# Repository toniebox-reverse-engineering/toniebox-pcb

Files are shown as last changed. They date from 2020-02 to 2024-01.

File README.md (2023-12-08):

# Toniebox PCB

Repository which will lead to a complete schematic of a Toniebox PCB. The schematic is done with KiCad.

View this project on [CADLAB.io](https://cadlab.io/project/2472). 

Source of CC3200 footprint: https://raw.githubusercontent.com/Turegano/CC3200/master/lib/CC3200.lib

## Table Of Contents
- [Toniebox PCB](#toniebox-pcb)
  - [Table Of Contents](#table-of-contents)
  - [Folders](#folders)
  - [Status](#status)
    - [Remaining Work](#remaining-work)
  - [Block Diagrams](#block-diagrams)
  - [Testpoints](#testpoints)

## Folders

* [datasheets](datasheets/)
* [doc](doc/): documentation
* [library](library/): KiCad libraries

## Status

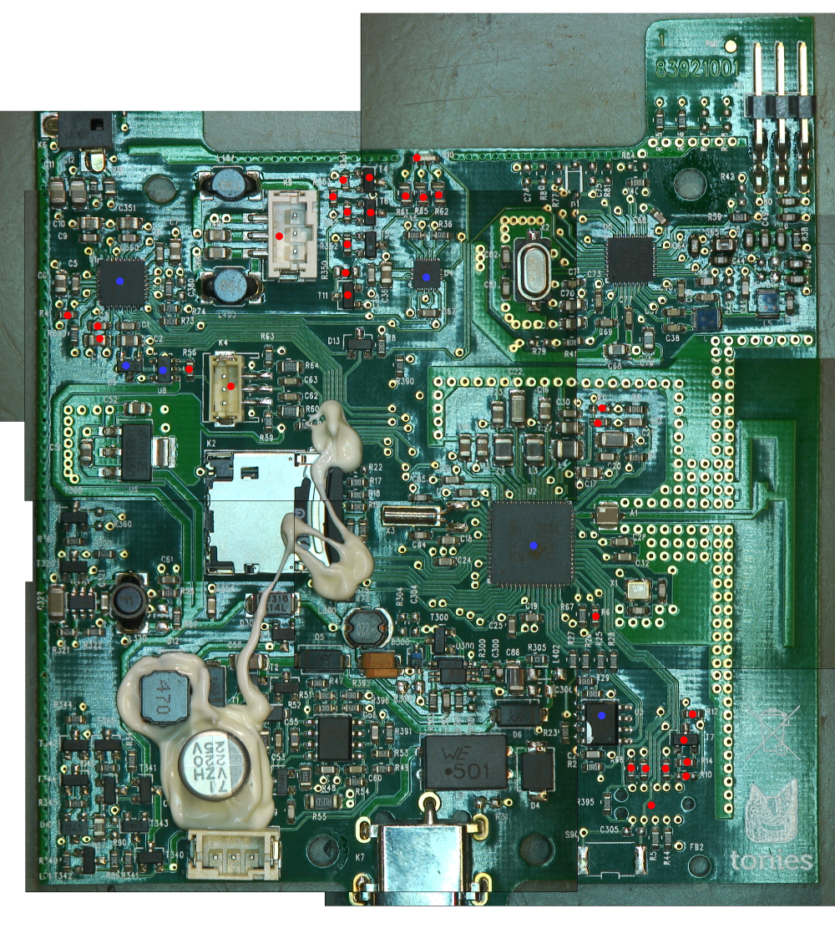
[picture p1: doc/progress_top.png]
Top


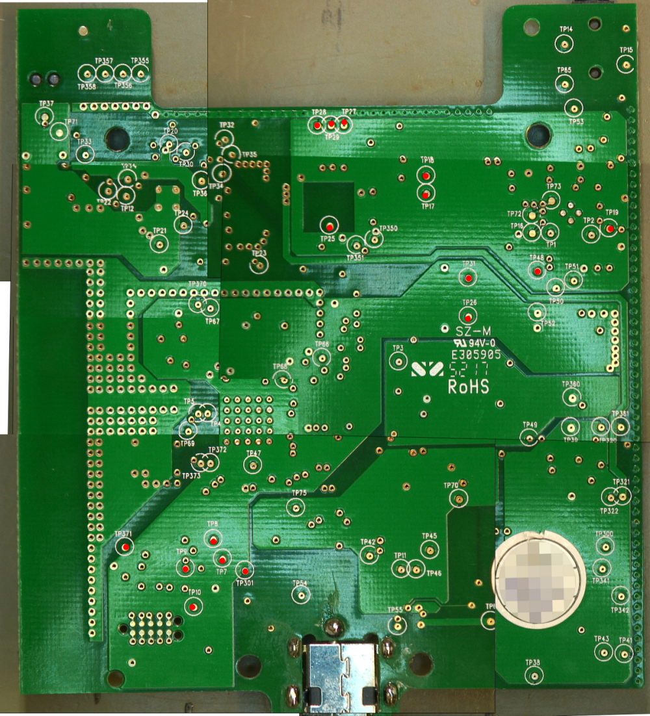
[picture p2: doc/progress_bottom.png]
Bottom


* red dot: fully documented
* blue dot: partially documented

### Remaining Work

* create subsheets for logical blocks
* create pinout of ASICs
* document remaining testpoints

  T1: NSS40200LTG

## Block Diagrams

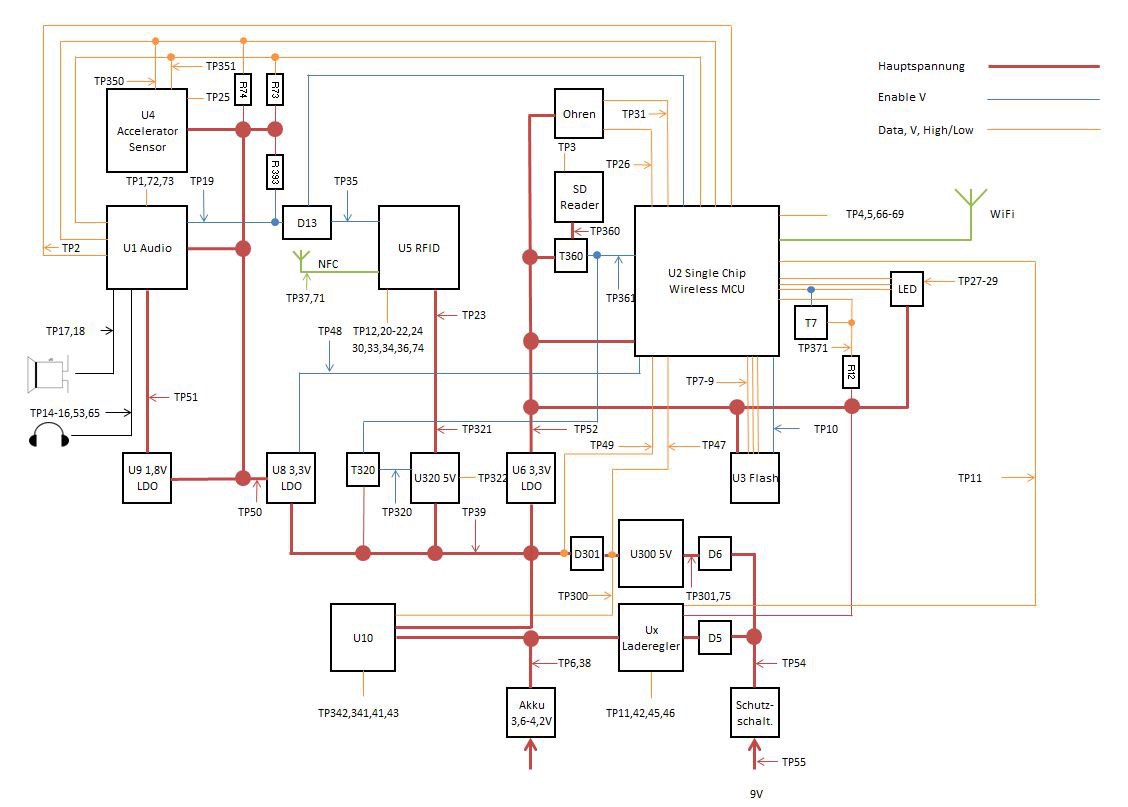
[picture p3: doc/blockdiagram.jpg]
Block diagram with testpoints


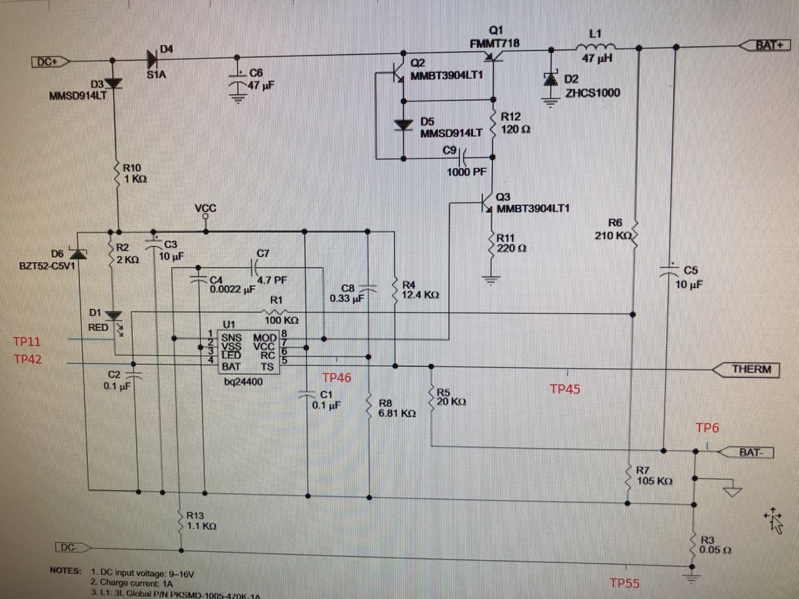
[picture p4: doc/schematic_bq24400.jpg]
BQ24400 (charge IC) with testpoints


## Testpoints

| TP | Connected to | Comment |
| ----- | --- | --- |
| TP1 | U1 MCLK | external master clock |
| TP2 | U1 GPIO1/ U2 pin 55 GPIO1 | |
| TP3 | K2 pin 9 | SD detect |
| TP4 | U2 pin 29 | ANT SEL1 Antenna Selection Control |
| TP5 | U2 pin 30 | ANT SEL2 Antenna Selection Control |
| TP6 | BQ24400 GND/Battery GND | Battery GND is connected with PCB GND via R55 (0R05) |
| TP7 | U2 pin 11/U3 pin 6/R27(?) | SCK |
| TP8 | U2 pin 12/U3 pin 5/R26(?) | SI |
| TP9 | U2 pin 13/U3 pin 2/R25(?) | SO |
| TP10  | U2 pin 14/U3 pin 8/R28(?) | VCC |
| TP11  | U7 pin 3 (~LED) | Charge status LED, connected to U6 output via 100k pull up and U2 pin 20 via 1k2 |
| TP12  | U5 ASK/OOK | can be configured as an output to provide the received analog signal output |
| TP14  | audio jack | |
| TP15  | audio jack | |
| TP16  | U1 VOL/MICDETECT | |
| TP17  | K9 pin 3/U1 | speaker+ |
| TP18  | K9 pin 2/U1 | speaker- |
| TP19  | U1 pin 31/D12/U2 pin 62 GPIO7/U5 EN | DAC reset |
| TP20  | U5 VDD_X | |
| TP21  | U5 VDD | |
| TP22  | U5 BG | |
| TP23  | U5 VIN | Voltage of U320, if faulty check TP321 |
| TP24  | U5 VDD_A | |
| TP25  | U4 pin 3 | Accelerometer DNC |
| TP26  | K4 pin 1/U2 pin 57/R60 (1k)(?)/R394 (1k2)(?)/ | ears, fed from regulator U6/TP52 |
| TP27  | D10 pin 1 | LED red - |
| TP28  | D10 pin 2 | LED green - |
| TP29  | D10 pin 3 | LED blue - |
| TP30  | U5 IO 5 | |
| TP31  | K4 pin 3/U2 pin 59/R64(1k)(?) | ears, fed from regulator U6/TP52 |
| TP32  | | |
| TP33  | U5 MOD | |
| TP34  | U5 SYS | |
| TP35  | U5 EN | When high NFC IC is enabled. If faulty check TP19. Fed by U8 via D13 (is connected to U2 GPIO7). |
| TP36  | U5 EN2 | |
| TP37  | NFC socket | |
| TP38  | K8 pin 3/T1/D12 (battery control circuit)/T340/T342 | bat+ |
| TP39  | U320 VIN, T320 collector voltage for U320 EN via R320; U6 VIN; U8 VIN | feeds U320, U6, U8 with VCC; enables U320 via T320 |
| TP41  | Circuit next to U10 | 0V w/o battery, ~ bat. Voltage w/ battery; output of T344; connected to U10; controls  T343, T342, T340 |
| TP42  | BQ24400 BAT input | |
| TP43  | U10 / | battery voltage after R89; w/ battery: voltage < bat voltage; w/ power supply 3.8 – 4.4V; check TP38 if not ok |
| TP45  | K8 pin 1/U7 pin 5 (TS) | temp sense; connected via R47 with BQ24400 and battery NTC. |
| TP46  | BQ24400 TIMER PROGRAM | |
| TP47  | U2 pin 8/output L300 via 1:1 voltage divider R75/R72 | Supervising U300+circuitry; measured between D301 and L300; 50% voltage via divider R75/R72 to U2 pin 8 |
| TP48  | U2 pin 61/U8 ENABLE via R56 (10k pulldown) | U2 enables LDO U8 with GPIO6. If U8 is not working (TP50) check U8 at TP39 |
| TP49  | U2 pin 60 | |
| TP50  | U8 VOUT/U9 VIN/U1 IOVDD/U1 HPVDD/SPKVDD/AVDD | 3V3 output of LDO U8, 1V8 input of LDO U9, T11, U4. 3V3 input U1; if not ok check TP48. |
| TP51  | U9 VOUT/U1 DVDP | 1V8 output of LDO U9. Feeds  U1 at PIN 3; if not ok check ENABLE at TP50 and input voltage at TP39. |
| TP52  | U6 VOUT 3V3/ U2 VIN IO1, VIN IO2, VIN DCDC ANA, VIN DCDC PA, VIN DCDC DIG, VD2 ANA2/ VCC for U3,T7, T360, T320, SV BQ24400 LED/ RGB LED | 3V3 output LDO U6: feeds U2, U3, T360 (TP360), TP320, LED output of BQ24400 (TP11) |
| TP53  | audio jack | |
| TP54  | VCC | Power supply voltage; if power supply is ok check L8 (SMT Common Mode Line Filter 2x500mH)  and D4 (15V TVS Diode) |
| TP55  | GND power jack | |
| TP65  | audio jack | |
| TP66  | U2 pin 43/pin 9/pin 56 | U2 internal voltage |
| TP67  | U2 pin 38/pin 36/pin 48/pin 25 | U2 internal voltage |
| TP68  | U2 pin 48 | U2 internal voltage |
| TP69  | U2 pin 24 | U2 internal voltage |
| TP70  | T9 | middle pin (SMD 13014) |
| TP71  | U5 VSS PA/VSS RF/VSS/VSS D/NFC connector outer contacts | |
| TP72  | U1 AIN1 | |
| TP73  | U1 AIN2 | |
| TP74  | U5 IRQ | |
| TP75  | U300 VIN | comes from R305 (0R). U300 generates voltage when operating with power supply; if not ok check TP301 |
| TP300 | U300 ISENS/T347 via R344 | U300 output voltage; main supply when connected to power supply; input voltage of voltage divider R344/R345 for U10. |
| TP301 | D6 | Main voltage after D6;if not ok check TP54 |
| TP320 | U320 ENABLE/T320 | ENABLE U320 from T320; T320 is supplied via R320 (470k) from D301 (TP39); T320 is controlled by U2 pin 58; if not ok check TP361 and supply voltage of TP39 |
| TP321 | U320 output/U5 input | U320 supplies U5; if not ok check TP320 and TP39 for supply voltage; if supply voltage check TP322 |
| TP322 | U320 feedback | Voltage for regulating output voltage of U320; output voltage of divider R321 (470k)/R322 (180k); should be 1.31V-1.51V; divider is fed by U320 output; if not ok check output TP321, input TP39, ENABLE TP320 |
| TP341 | U10 circuitry | ;output of T347; controls T346, T345, T341;  LOW when operating with power supply; ~ bat voltage when operating with battery; check TP342 and TP38 |
| TP342 | U10 circuitry/voltage divider R344/R345 | Voltage divider R344/R345; fed from output of U300; triggers T344, T347 getriggert; operating with power supply: 1V; battery mode: 0V;check  TP300 |
| TP350 | U2 pin 3 | I2C_SCL |
| TP351 | U2 pin 4 | I2C_SDA |
| TP355 | config(?) R connected to GND | |
| TP356 | config(?) R connected to GND | |
| TP357 | config(?) R connected to GND | |
| TP358 | config(?) R connected to GND | |
| TP360 | K2 pin4 | SD VDD;T360 switches  3V3 of U6; T360 is controlled by  U2 GPIO3 PIN58;  check TP361 |
| TP361 | T320/T360 (voltage) | T320 switches ENABLE of U320 / T360 controls voltage SD card |
| TP370 | U2 pin 34 SOP1 | |
| TP371 | U2 pin 35 SOP0 | |
| TP372 | U2 pin 17 TDO | |
| TP373 | U2 pin 18 | |

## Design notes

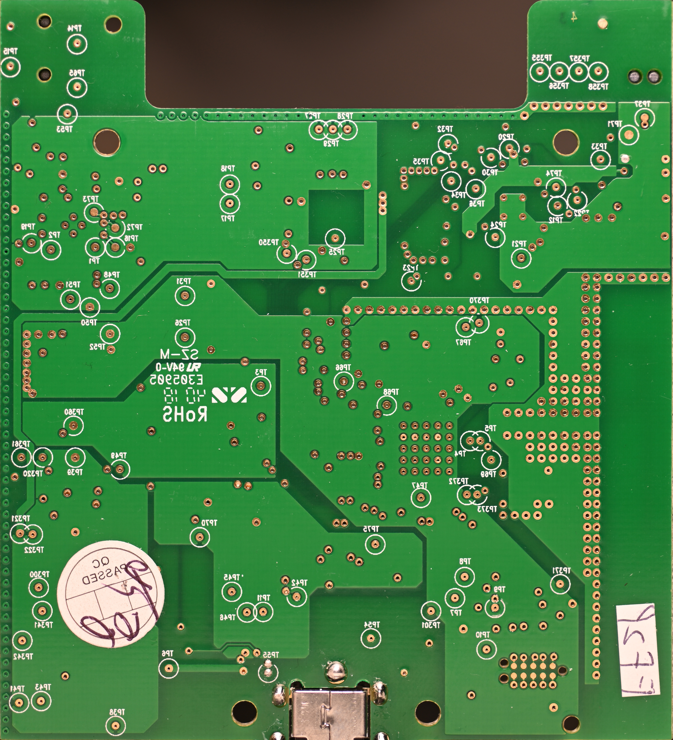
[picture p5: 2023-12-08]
v1-v2/TonieboxCC3200-back2.jpg

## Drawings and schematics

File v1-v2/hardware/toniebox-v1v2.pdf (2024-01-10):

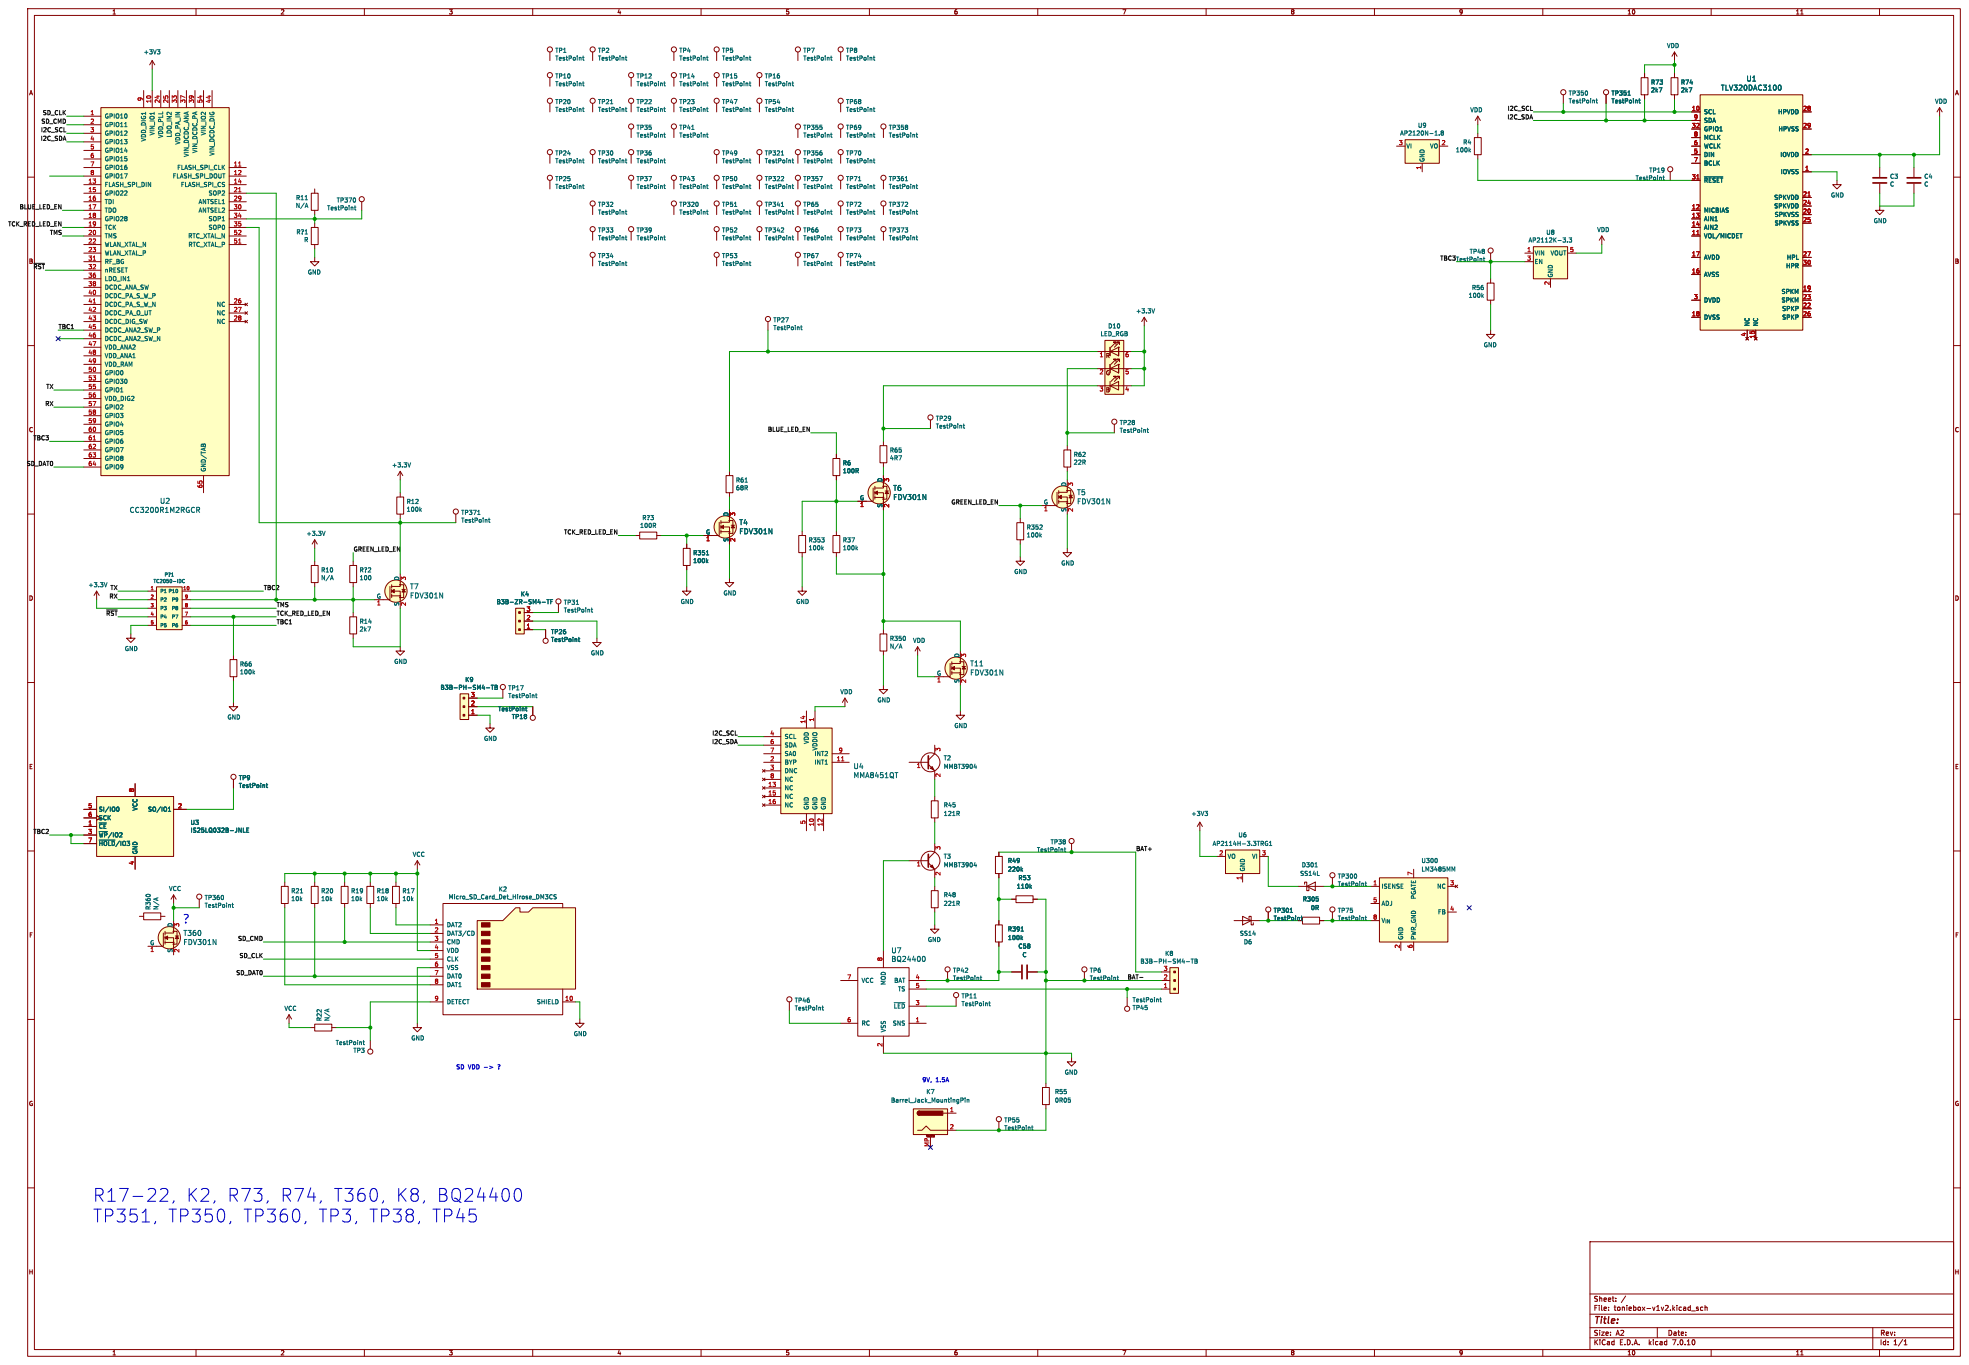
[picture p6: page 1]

TP51 TestPoint TP34 TestPoint TP30 TestPoint TP24 TestPoint

1 GND 10 INT1 11 GND 12 NC 13 VDD 14 NC 15 NC 16 BYP 2 DNC 3 SCL 4 GND

4 SI/IO0 5 SCK 6 ~{HOLD}/IO3 7 VCC

2 ~{LED} 3 BAT 4 TS 5 RC 6 VCC 7 MOD

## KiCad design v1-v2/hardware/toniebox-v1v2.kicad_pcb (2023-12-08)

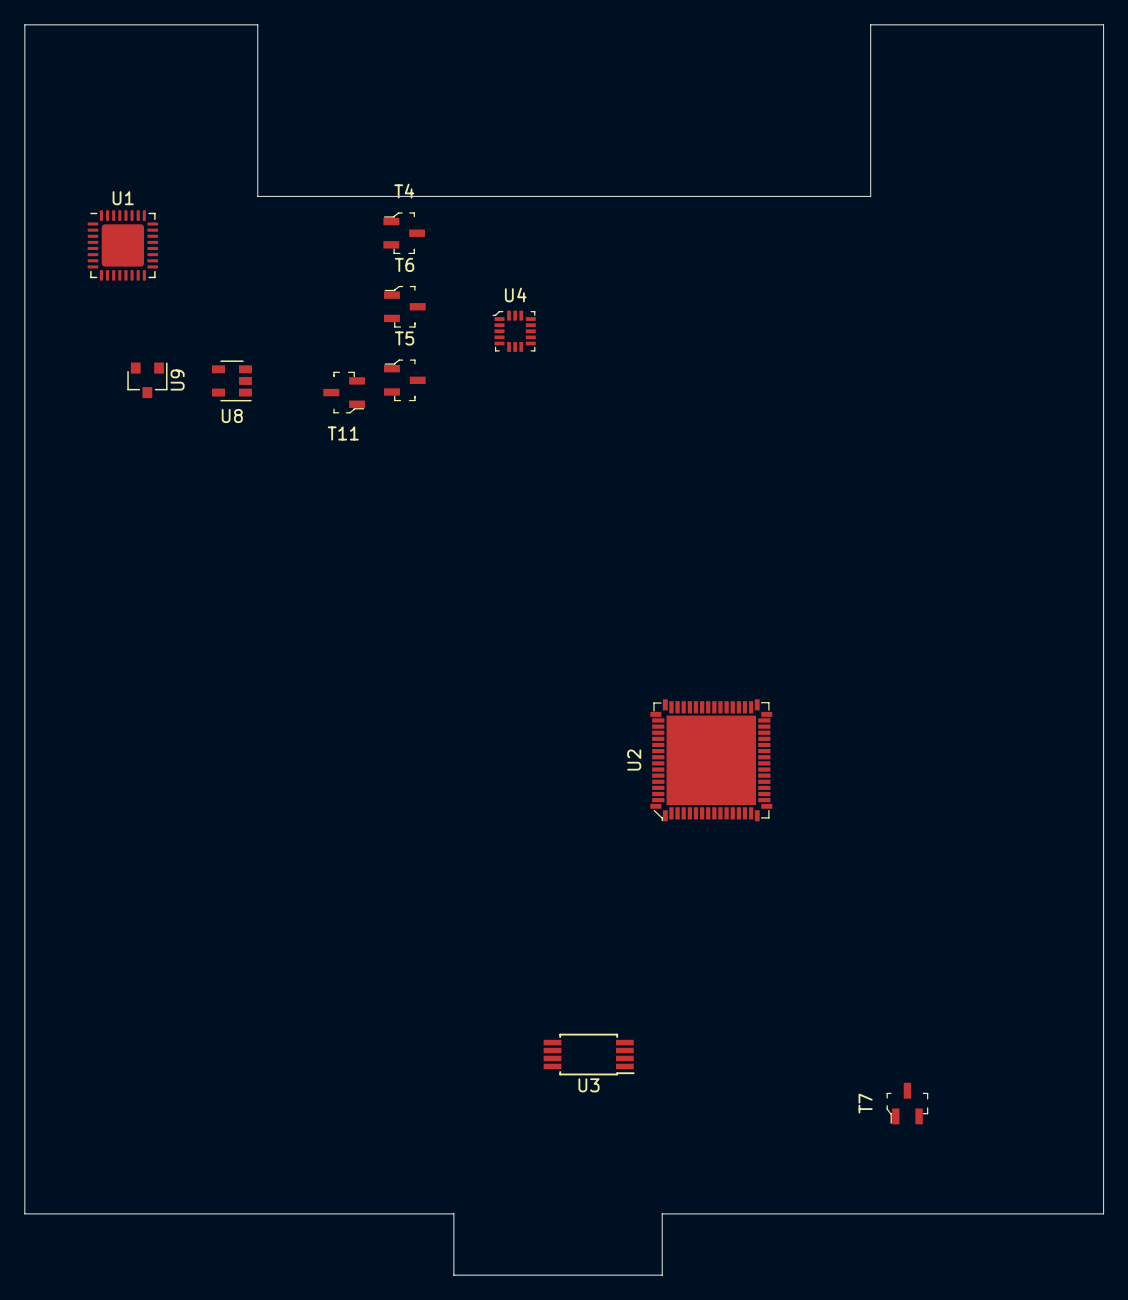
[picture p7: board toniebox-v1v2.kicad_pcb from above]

Board: 2 copper layers, 88.0 x 102.0 mm, 11 parts (0 on the bottom side), 7 nets, no tracks yet.

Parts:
T4, T5, T6, T7, T11: FDV301N; SOT-23-3
U1: TLV320DAC3100; Texas_S-PVQFN-N32_EP3.45x3.45mm
U2: CC3200R1M2RGCR; VFQFN-64-1EP_9x9mm
U3: IS25LQ032B-JNLE; TSSOP-8_4.4x3mm_P0.65mm
U4: MMA8451QT; VQFN-16_3x3mm
U8: AP2112K-3.3; SOT-23-5
U9: AP2120N-1.8; SOT-23

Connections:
/TBC2: U3.3, U3.7
/TBC3: U2.61, U8.3
GND: T4.2, T5.2, T7.2, T11.2, U1.1
unnamed: T7.1, U2.21
unnamed: T7.3, U2.35
unnamed: T6.2, T11.3
VDD: T11.1, U1.2, U4.1, U8.5

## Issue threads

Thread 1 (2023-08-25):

Diode next to Audio Jack?

ggrote, 2023-08-25:
Thanks for the project, do you know what this component is? I think it's a diode, but not sure which one.
I got a Toniebox with a exploded diode and I want to replace it.
Thanks in advance!
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

SciLor, 2023-08-25:
This spot is very unusual.
Usually, those parts only explode if they run on too much voltage/current. So the root problem will be something different. Therefore, I would check the power supply and the different voltage regulation parts.

ggrote, 2023-08-25:
The first picture was from a Toniebox PCB that is okay. Here is a picture of the PCB with the exploded Diode:
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

Could it be if someone puts a power supply with an audio jack cable into the headphone jack?

SciLor, 2023-08-25:
This could be a possible reason.
Does the box still boot? (Not just glows green!)

ggrote, 2023-08-25:
The Box starts up, the Led is blinking red and there is no sound.

ggrote, 2023-08-25:
I'm in the telegram group now. If you want you can delete the issue as it's not an issue with the github project.
Just got no other way to contact you. :)

Closed 2023-08-25.

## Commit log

2020-01-20 inital commit
    [toniebox.kicad_pcb, toniebox.sch]
2020-01-20 add led
    [toniebox.sch]
2020-01-27 adding testpoints
    [toniebox.sch]
2020-01-28 LED circuit, more testpoints
    [toniebox.sch]
2020-01-29 testpoints, LDOs
    [toniebox.sch]
2020-02-01 add datasheet, progress images, library
    [toniebox.sch]
2020-02-06 add mosfet datasheet, more ICs
    [toniebox.kicad_pcb, toniebox.sch]
2020-02-20 sd card
    [toniebox.sch]
2020-02-22 battery, ear connectors;datasheets
    [toniebox.sch]
2023-12-08 migrate to kicad 7, add testpoints
    [toniebox.kicad_pcb, toniebox.sch]
2023-12-08 add libraries
    [toniebox-v1v2.kicad_pcb, toniebox-v1v2.kicad_sch]
2023-12-26 wip: schematic
    [toniebox-v1v2.kicad_sch]
2024-01-10 add schematic pdf export
